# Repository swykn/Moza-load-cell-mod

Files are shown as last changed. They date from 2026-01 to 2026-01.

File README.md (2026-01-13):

# Moza Load Cell Mod

## English

This project converts the **brake pedal of the Moza CR-P Lite Pedals into a load-cell based system**.  
The goal is to enable force-based braking input and achieve a more realistic driving feel.

---

### Hardware Overview

An **Arduino Pro Micro compatible board** is used as a  
**USB HID joystick controller**.

Pro Micro compatible board used in this project:  
https://www.amazon.co.jp/dp/B0DHGTNMHH

The load cell used is the **Akizuki Denshi 100 kg load cell (SC301A)**.  
https://akizukidenshi.com/catalog/g/g112036/  
https://www.alibaba.com/suppliersubdomainalibabacom/product-detail/SC301A-S-Type-Load-Cell-Pull-60183532797.html  

The load cell amplifier is **SparkFun Qwiic Scale – NAU7802**.  
It was selected to enable **high-speed sampling at 320 SPS**, which is not possible with the HX711.  
https://www.sparkfun.com/sparkfun-qwiic-scale-nau7802.html

The system uses:
- **5 V logic (Arduino Pro Micro)**
- **3.3 V logic (NAU7802)**

Therefore, **power conversion (5V → 3.3V)** and **I²C level shifting** are required.

---

### Power Conversion (5V → 3.3V)

A dedicated **5V → 3.3V power module** is used.  
The generated **3.3 V is supplied to both the NAU7802 and the LV pin of the level shifter**.

Amazon (Japan):  
https://www.amazon.co.jp/dp/B0BJJBG8C4

**Important**
- NAU7802 is **not 5V tolerant**
- Never connect NAU7802 directly to 5 V
- All GND connections must be common

---

### Level Shifter Used

A **BSS138-based I²C bidirectional level shifter** is used.

Amazon (Japan):  
https://www.amazon.co.jp/dp/B086WWCJGQ

Any equivalent bidirectional I²C level shifter can be used.

---

### Wiring (I²C Level Shifting)

Only **SDA, SCL, VCC, and GND** are required.

- HV side: **5 V (Arduino Pro Micro)**
- LV side: **3.3 V (from power module)**

| Arduino Pro Micro (5V) | Level Shifter (HV) | Level Shifter (LV) | NAU7802 (3.3V) |
|---|---|---|---|
| SDA | HV1 | LV1 | SDA |
| SCL | HV2 | LV2 | SCL |
| GND | GND | GND | GND |
| — | — | LV (3.3V) | 3.3V |

---

### ⚠ WARNING: HV / LV Connection

**Do NOT swap HV and LV connections.**

- **HV must be 5 V**
- **LV must be 3.3 V**

Reversing HV and LV may:
- Break I²C communication
- Permanently damage the NAU7802
- Damage the level shifter itself

Always double-check before powering on.

---

### Wiring Diagram (SVG)

Wiring diagram

- Open SVG directly: [docs/wiring.svg](docs/wiring.svg)

---

## Files

### Firmware

- **loadcell_brake.ino**  
Arduino firmware for the load-cell brake pedal.  
Compile and upload this sketch using the Arduino IDE.  
After flashing, the board is recognized as a USB HID joystick.

### 3D Printed Parts

- **top.stl**  
- **bottom.stl**  

These parts clamp the load cell and allow it to be mounted inside the pedal assembly.

### Design Source

- **sr-p lite pedal loadcell mount v1.f3d**  

Fusion 360 design file used to generate the STL files above.

---

## Required Libraries

The following Arduino libraries are required to compile the firmware:

- **Arduino Joystick Library**  
  https://github.com/MHeironimus/ArduinoJoystickLibrary

- **SparkFun Qwiic Scale NAU7802 Library**  
  https://github.com/sparkfun/SparkFun_Qwiic_Scale_NAU7802_Arduino_Library

Make sure both libraries are installed before compiling.

---

## Arduino IDE Setup (SparkFun AVR Boards)

To compile and upload the firmware correctly, the **SparkFun AVR Boards** definition is used.

1. Open **File > Preferences**  
   Add the following URL to **Additional Boards Manager URLs**:
https://raw.githubusercontent.com/sparkfun/Arduino_Boards/master/IDE_Board_Manager/package_sparkfun_index.json

2. Open **Tools > Board > Boards Manager**, search for **sparkfun**,  
and install **SparkFun AVR Boards by SparkFun Electronics**.

3. Select the board:  
**Tools > Board > SparkFun AVR Boards > SparkFun Pro Micro**

4. Select the processor:  
**Tools > Processor > ATmega32U4 (5V, 16 MHz)**

---

## Reset and Enter Bootloader

If the board does not appear for upload or the upload fails:

1. With the board connected to the PC, **short RST and GND twice quickly**  
(on this board, **pin 3 and pin 4**).

2. The bootloader will start and the board will reappear briefly.  
**Upload the sketch immediately** while the bootloader is active.

---

### Photos

| Description | Link |
|---|---|
| PCB (top) | [docs/pcb_top.jpg](docs/pcb_top.jpg) |
| PCB (bottom) | [docs/pcb_bottom.jpg](docs/pcb_bottom.jpg) |
| With 3D printed parts | [docs/with_3d_parts.jpg](docs/with_3d_parts.jpg) |
| Installed in pedal | [docs/installed_in_pedal.jpg](docs/installed_in_pedal.jpg) |
| Overall finished assembly | [docs/final_overview.jpg](docs/final_overview.jpg) |

<details>
<summary>Show photo previews</summary>

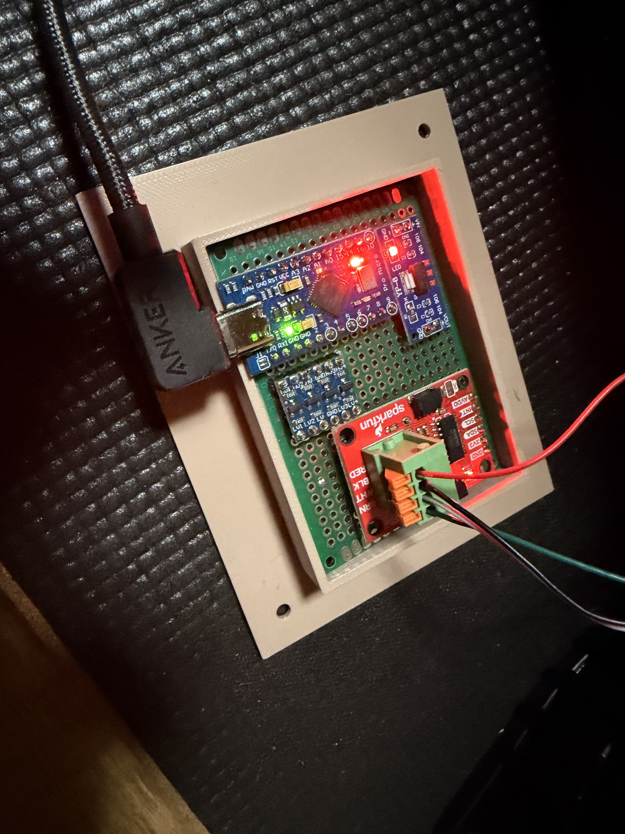
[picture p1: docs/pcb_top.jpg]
PCB top

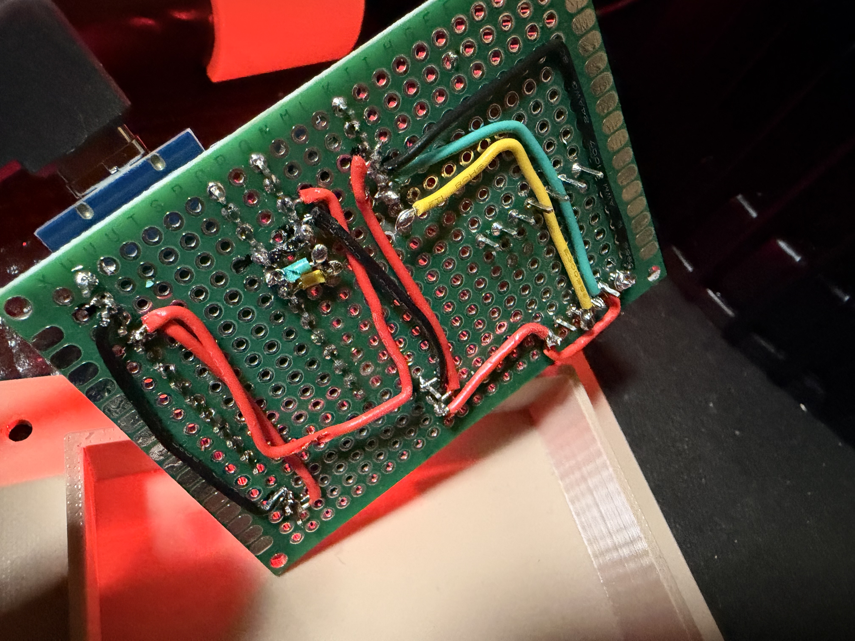
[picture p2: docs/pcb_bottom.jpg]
PCB bottom

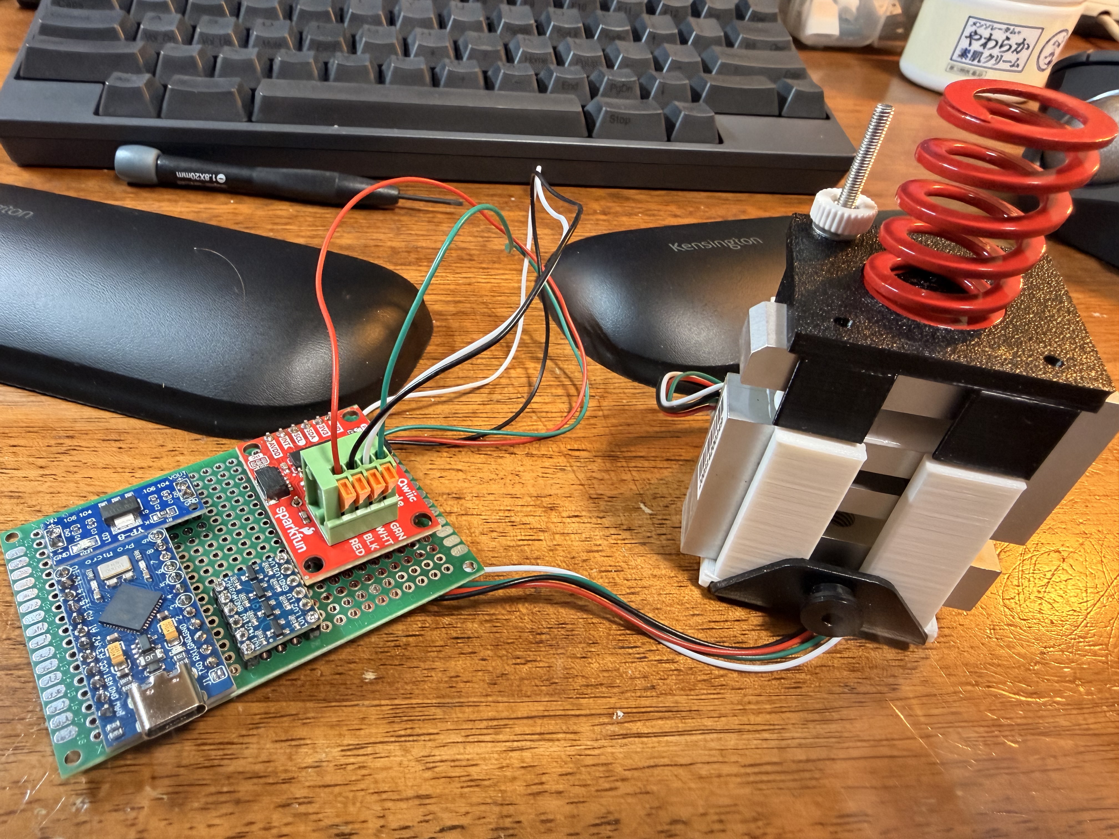
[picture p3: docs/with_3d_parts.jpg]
With 3D printed parts

Installed in pedal
Final overview

</details>

---

### Usage

When connected to Windows, the device is recognized as a  
**USB joystick with one axis and one button**.

To calibrate the maximum brake force:
- Press the brake **firmly for about 2 seconds**

Calibration is performed automatically.

---

### Notes and Warnings

The **spring terminals on the SparkFun Qwiic Scale – NAU7802 are unreliable**.  
Even if a wire appears to be properly inserted, electrical contact may fail.

It is strongly recommended to:
- Solder pin headers, or
- Replace the terminals with more reliable connectors

---
## 日本語

このプロジェクトは、**Moza CR-P Lite Pedals のブレーキペダルをロードセル方式に改造する**ものです。  
踏力に応じた入力を可能にし、より実車に近いブレーキフィールを得ることを目的としています。

---

### ハードウェア構成

本プロジェクトでは、**Arduino Pro Micro 互換ボード**を  
**USB HID ジョイスティックコントローラ**として使用しています。

使用した Pro Micro 互換ボード：  
https://www.amazon.co.jp/dp/B0DHGTNMHH

ロードセルには **秋月電子 100kg ロードセル（SC301A）** を使用しています。  
https://akizukidenshi.com/catalog/g/g112036/

ロードセルアンプには **SparkFun Qwiic Scale – NAU7802** を採用しました。  
HX711 では不可能な **320 SPS の高サンプリングレート**での取得を目的として選定しています。  
https://www.sparkfun.com/sparkfun-qwiic-scale-nau7802.html
https://www.switch-science.com/products/5539

本構成では、
- **5V 系（Arduino Pro Micro）**
- **3.3V 系（NAU7802）**

の 2 系統のロジック電圧を使用するため、  
**電源変換（5V → 3.3V）** および **I²C レベル変換** が必要になります。

---

### 電源変換（5V → 3.3V）

**5V → 3.3V の電源変換モジュール**を使用しています。  
生成した **3.3V は NAU7802 とレベル変換モジュールの LV ピンの両方に供給**します。

使用した電源変換モジュール：  
https://www.amazon.co.jp/dp/B0BJJBG8C4

**重要**
- NAU7802 は **5V 非対応（3.3V 専用）** です  
- NAU7802 に 5V を直接接続しないでください  
- GND は必ずすべて共通にしてください  

---

### 使用したレベル変換モジュール

**BSS138 MOSFET を使用した I²C 双方向レベル変換モジュール**を使用しています。

Amazon（日本）：  
https://www.amazon.co.jp/dp/B086WWCJGQ

同等仕様の **双方向 I²C レベル変換モジュール** であれば代替可能です。

---

### 配線（I²C レベル変換）

必要な信号は **SDA / SCL / VCC / GND** のみです。

- HV 側：**5V（Arduino Pro Micro）**
- LV 側：**3.3V（電源変換モジュール）**

| Arduino Pro Micro (5V) | レベル変換（HV） | レベル変換（LV） | NAU7802 (3.3V) |
|---|---|---|---|
| SDA | HV1 | LV1 | SDA |
| SCL | HV2 | LV2 | SCL |
| GND | GND | GND | GND |
| — | — | LV (3.3V) | 3.3V |

---

### ⚠ 警告：HV / LV の逆接続について

**HV と LV を逆に接続しないでください。**

- **HV は必ず 5V**
- **LV は必ず 3.3V**

逆接続すると、
- I²C 通信が成立しない  
- NAU7802 が恒久的に破損する  
- レベル変換モジュール自体が破損する  

可能性があります。  
通電前に必ず配線を再確認してください。

---

### 配線図（SVG）

配線図

- SVG を直接開く: [docs/wiring.svg](docs/wiring.svg)

---

## ファイル構成

### ファームウェア

- **loadcell_brake.ino**  
  ロードセル式ブレーキ用の Arduino ファームウェアです。  
  Arduino IDE でコンパイルし、ボードに書き込んでください。  
  書き込み後は USB HID ジョイスティックとして認識されます。

### 3Dプリント部品

- **top.stl**  
- **bottom.stl**  

ロードセルを挟み込み、ペダル内部に固定するための部品です。

### 設計データ

- **sr-p lite pedal loadcell mount v1.f3d**  

上記 STL ファイルの元となった Fusion 360 の設計データです。

---

## 必要なライブラリ

ファームウェアをコンパイルするには、以下の Arduino ライブラリが必要です。

- **Arduino Joystick Library**  
  https://github.com/MHeironimus/ArduinoJoystickLibrary

- **SparkFun Qwiic Scale NAU7802 Library**  
  https://github.com/sparkfun/SparkFun_Qwiic_Scale_NAU7802_Arduino_Library

コンパイル前に、必ず両方のライブラリを Arduino IDE にインストールしてください。

---

## Arduino IDE 設定（SparkFun AVR Boards）

本プロジェクトでは **SparkFun AVR Boards** のボード定義を使用します。

1. **File > Preferences（ファイル > 環境設定）** を開き、  
   **Additional Boards Manager URLs** に以下を追加します。  
https://raw.githubusercontent.com/sparkfun/Arduino_Boards/master/IDE_Board_Manager/package_sparkfun_index.json

2. **Tools > Board > Boards Manager** を開き、  
**sparkfun** で検索し、  
**SparkFun AVR Boards by SparkFun Electronics** をインストールします。

3. ボードを選択します。  
**Tools > Board > SparkFun AVR Boards > SparkFun Pro Micro**

4. プロセッサを選択します。  
**Tools > Processor > ATmega32U4 (5V, 16 MHz)**

---

## リセットしてブートローダーを起動

書き込み時にボードが表示されない、またはアップロードに失敗する場合：

1. PC に接続した状態で、**RST と GND を素早く 2 回ショート**させます  
（このボードでは **3 番ピンと 4 番ピン**）。

2. ブートローダーが起動し、短時間だけボードが認識されます。  
**その間にスケッチを書き込んでください**。

---

### 写真

| 内容 | リンク |
|---|---|
| 基板（表） | [docs/pcb_top.jpg](docs/pcb_top.jpg) |
| 基板（裏） | [docs/pcb_bottom.jpg](docs/pcb_bottom.jpg) |
| 3Dプリント部品と組み合わせた状態 | [docs/with_3d_parts.jpg](docs/with_3d_parts.jpg) |
| ペダルに組み込んだ状態 | [docs/installed_in_pedal.jpg](docs/installed_in_pedal.jpg) |
| 完成状態全体 | [docs/final_overview.jpg](docs/final_overview.jpg) |

<details>
<summary>写真プレビュー</summary>

基板 表
基板 裏
3D部品組合せ
ペダル組込み
完成全体

</details>

---

### 使用方法

Windows に接続すると、  
**1軸＋1ボタンの USB ジョイスティック**として認識されます。

最大踏力のキャリブレーションは、  
**ブレーキを約 2 秒間、強めに踏み込む**ことで自動的に行われます。

---

### 注意事項

**SparkFun Qwiic Scale – NAU7802 のスプリングターミナルは接触不良を起こしやすい**です。  
見た目上は接続できていても、実際には導通していないことがあります。

- ピンヘッダをはんだ付けする  
- 信頼性の高い端子に交換する  

ことを強く推奨します。

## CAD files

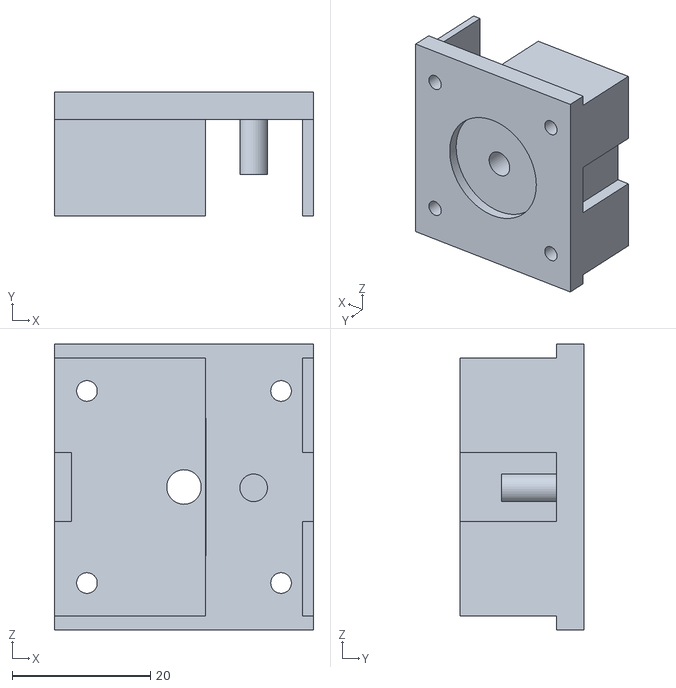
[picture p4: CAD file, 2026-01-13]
top.stl
37.5 x 18.0 x 41.4

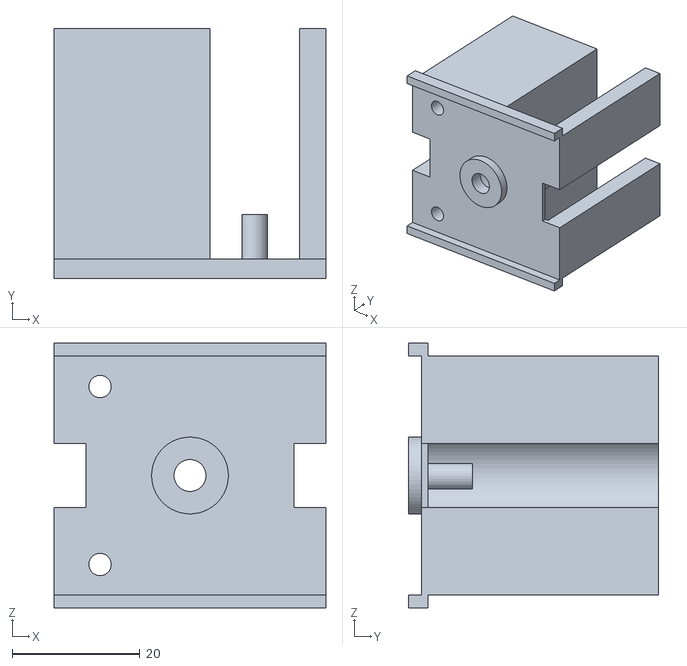
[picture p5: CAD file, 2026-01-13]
bottom.stl
42.5 x 39.0 x 41.4

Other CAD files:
sp-r lite pedal loadcell mount v1.f3d

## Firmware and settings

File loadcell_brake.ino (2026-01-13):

#include <Wire.h>
#include "SparkFun_Qwiic_Scale_NAU7802_Arduino_Library.h"
#include <Joystick.h>

NAU7802 scale;

// --- HID: Y軸 + ボタン1個（joydevに出やすくするため） ---
// --- HID: Y axis + 1 button (to show up easily as a joydev device) ---
Joystick_ joy(
  JOYSTICK_DEFAULT_REPORT_ID,
  JOYSTICK_TYPE_JOYSTICK,
  1, 0,                 // buttons=1, hat=0
  false, true, false,   // X=false, Y=true, Z=false
  false, false, false,  // Rx,Ry,Rz
  false, false,         // rudder, throttle
  false, false, false   // accelerator, brake, steering
);

// ===== 調整パラメータ =====
// ===== Tuning parameters =====
#define DEBUG_SERIAL 1       // 0:Serial出さない  1:20Hzで出す
                           // 0: disable Serial output, 1: print at 20Hz

// I2CとNAU7802設定
// I2C and NAU7802 settings
const uint8_t  GAIN   = NAU7802_GAIN_128;
const uint8_t  SPS    = NAU7802_SPS_320;

// 0..1023 出力（Sim側でキャリブする前提）
// Output 0..1023 (assumes calibration on the simulator side)
const uint16_t AXIS_MAX = 1023;

// デッドゾーン（0..1023）
// Dead zone (0..1023)
const uint16_t DEADZONE = 8;

// カーブ: 0=リニア, 1=二次（踏み始め穏やか）
// Curve: 0=linear, 1=quadratic (gentler at initial press)
const uint8_t CURVE_MODE = 0;

// ビットシフトIIR（最軽量）
// Bit-shift IIR (lightest-weight)
// kが小さいほど速い。K_UPは踏み込み側、K_DNは戻り側。
// Smaller k = faster response. K_UP for press (rising), K_DN for release (falling).
const uint8_t K_UP = 0;  // 0=完全追従（最速） 1=速い 2=普通
                         // 0=full follow (fastest), 1=fast, 2=normal
const uint8_t K_DN = 3;  // 戻りを安定させる（大きいほど遅い）
                         // Stabilize release (larger = slower)

// 値の向き：踏むと増えるようにする（必要なら1）
// Direction: make value increase when pressed (set to 1 if needed)
const uint8_t INVERT_RAW = 1;

// キャリブ
// Calibration
int32_t raw0   = 0;       // 無荷重ゼロ点（起動時平均で決定）
// raw0: zero point at no load (determined by averaging at startup)
int32_t rawMax = 950000;  // 最大踏力（filtの最大実測に合わせて調整推奨）
// rawMax: max pedal force (recommended to tune to observed max of filt)

// ==== rawMax 自動キャリブ ====
// ==== Auto-calibration for rawMax ====
#define AUTO_CAL_MAX 1

// キャリブ開始判定（軸値）
// Auto-cal start threshold (axis value)
const uint16_t CAL_START_AXIS = 200;   // 0..1023のうち、この値を超えたら「踏んだ」とみなす
                                       // Consider "pressed" when exceeding this value (0..1023)
const uint16_t CAL_MARGIN_PCT = 2;     // 確定rawMaxに上乗せするマージン（%）
                                       // Margin to add on top of finalized rawMax (%)
const uint16_t CAL_WINDOW_MS  = 2000;  // 最大値を集める時間（ms）
                                       // Time window to capture the peak (ms)

static bool calDone = false;
static bool calRunning = false;
static uint32_t calT0 = 0;
static int32_t calMaxFilt = 0;

// 安全ガード（極端な値を防ぐ）
// Safety guards (prevent extreme values)
const int32_t RAWMAX_MIN = 50000;      // 最低レンジ（環境により調整）
                                       // Minimum range (adjust per environment)
const int32_t RAWMAX_MAX = 2000000;    // 上限（あり得ない値で暴走しないように）
                                       // Upper limit (avoid runaway from impossible values)


// ---- 補助関数 ----
// ---- Helper functions ----
static int32_t measureZero(NAU7802 &s, int samples)
{
  int64_t acc = 0;
  int n = 0;
  while (n < samples) {
    if (s.available()) {
      acc += s.getReading();
      n++;
    }
  }
  return (int32_t)(acc / samples);
}

static inline uint16_t clampU16(uint32_t v, uint16_t lo, uint16_t hi)
{
  if (v < lo) return lo;
  if (v > hi) return hi;
  return (uint16_t)v;
}

// 生値（int32）→ 0..1023（線形）
// Raw value (int32) -> 0..1023 (linear)
static inline uint16_t rawToAxis(int32_t v, int32_t z, int32_t m)
{
  // v: raw or filt
  int32_t dv = v - z;
  if (dv <= 0) return 0;

  int32_t span = m - z;
  if (span <= 1) return 0;

  if (dv >= span) return AXIS_MAX;

  // 32bitで安全に：dv * 1023 / span
  // Safe in 32-bit: dv * 1023 / span
  uint32_t out = (uint32_t)dv * (uint32_t)AXIS_MAX;
  out /= (uint32_t)span;
  return (uint16_t)out;
}

// デッドゾーン＋（任意）カーブ
// Dead zone + (optional) curve shaping
static inline uint16_t shapeAxis(uint16_t x)
{
  if (x <= DEADZONE) return 0;

  // デッドゾーン分を除いて再スケール
  // Rescale after removing the dead-zone portion
  uint32_t y = (uint32_t)(x - DEADZONE) * AXIS_MAX;
  y /= (AXIS_MAX - DEADZONE);
  uint16_t r = (uint16_t)y;

  if (CURVE_MODE == 0) {
    return r; // linear
  } else {
    // quadratic: r^2 / 1023
    return (uint16_t)(((uint32_t)r * (uint32_t)r) / AXIS_MAX);
  }
}

void setup()
{
#if DEBUG_SERIAL
  Serial.begin(115200);
  Serial.println("DEBUG MODE!!");
#endif

  Wire.begin();

  while (!scale.begin()) {
#if DEBUG_SERIAL
    Serial.println("NAU7802 not detected");
#endif
    delay(500);
  }

  scale.setGain(GAIN);
  scale.setSampleRate(SPS);
  scale.calibrateAFE();

  // 無荷重で起動してゼロ点取得
  // Start with no load to measure and set the zero point
  raw0 = measureZero(scale, 64);

  // HID初期化
  // Initialize HID
  joy.setYAxisRange(0, AXIS_MAX);
  joy.begin();

#if DEBUG_SERIAL
  Serial.print("raw0=");   Serial.print(raw0);
  Serial.print(" rawMax=");Serial.println(rawMax);
  Serial.println("AutoCal: press brake firmly for about 2 seconds to calibrate max.");
#endif
}

void loop()
{
  if (!scale.available()) return;

  int32_t raw = scale.getReading();
  if (INVERT_RAW) raw = -raw;

  // --- ビットシフトIIR（最軽量） ---
  // --- Bit-shift IIR (lightest-weight) ---
  static int32_t filt = 0;
  int32_t diff = raw - filt;
  if (diff > 0) {
    // 踏み込み（上り）を速く
    // Faster on press (rising edge)
    if (K_UP == 0) filt = raw;
    else filt += (diff >> K_UP);
  } else {
    // 戻り（下り）を遅く
    // Slower on release (falling edge)
    filt += (diff >> K_DN);
  }

  // 0..1023へ
  // Convert to 0..1023
  uint16_t axis = rawToAxis(filt, raw0, rawMax);
  axis = shapeAxis(axis);

#if AUTO_CAL_MAX
  // rawMax確定前だけ実行
  // Run only until rawMax is finalized
  if (!calDone) {
    // キャリブ開始条件：ある程度踏み込んだら開始
    // Start condition: begin once pressed beyond a threshold
    if (!calRunning && axis > CAL_START_AXIS) {
      calRunning = true;
      calT0 = millis();
      calMaxFilt = filt;
#if DEBUG_SERIAL
      Serial.println("AutoCal: started");
#endif
    }

    // キャリブ実行中：最大filtを追跡
    // During auto-cal: track maximum filt
    if (calRunning) {
      if (filt > calMaxFilt) calMaxFilt = filt;

      // 時間経過で確定
      // Finalize after the time window elapses
      if (millis() - calT0 >= CAL_WINDOW_MS) {
        calRunning = false;
        calDone = true;

        // マージン付け（%）
        // Add margin (%)
        int32_t m = calMaxFilt + (calMaxFilt * (int32_t)CAL_MARGIN_PCT) / 100;

        // ガード
        // Guard rails
        if (m < RAWMAX_MIN) m = RAWMAX_MIN;
        if (m > RAWMAX_MAX) m = RAWMAX_MAX;

        rawMax = m;

#if DEBUG_SERIAL
        Serial.print("AutoCal: done rawMax=");
        Serial.println(rawMax);
#endif
      }
    }
  }
#endif

  // HID更新（毎回送る：体感優先）
  // Update HID (send every time for responsiveness)
  joy.setYAxis(axis);

  // ボタン：踏み込みがある程度以上でON（任意）
  // Button: ON when pressed beyond a threshold (optional)
  joy.setButton(0, axis > 20);

#if DEBUG_SERIAL
  // Serialは20Hzのみ。32bit生値は重いので>>8して16bit相当にして出す
  // Serial output at 20Hz only. 32-bit raw is heavy, so shift >>8 to print ~16-bit values.
  static uint32_t lastPrint = 0;
  uint32_t now = millis();
  if (now - lastPrint >= 50) { // 20Hz
    lastPrint += 50;
    int16_t r16 = (int16_t)(raw >> 8);
    int16_t f16 = (int16_t)(filt >> 8);

    Serial.print("r16="); Serial.print(r16);
    Serial.print(" f16="); Serial.print(f16);
    Serial.print(" out="); Serial.println(axis);
  }
#endif
}

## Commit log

2026-01-13 Revise README for Moza Load Cell Mod project
    Updated README to provide detailed project information, including hardware overview, wiring instructions, and usage notes.
2026-01-13 README.md を更新
